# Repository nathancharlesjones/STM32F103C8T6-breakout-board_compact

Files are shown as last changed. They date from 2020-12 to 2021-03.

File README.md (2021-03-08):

# STM32F103C8T6 Breakout Board - Compact

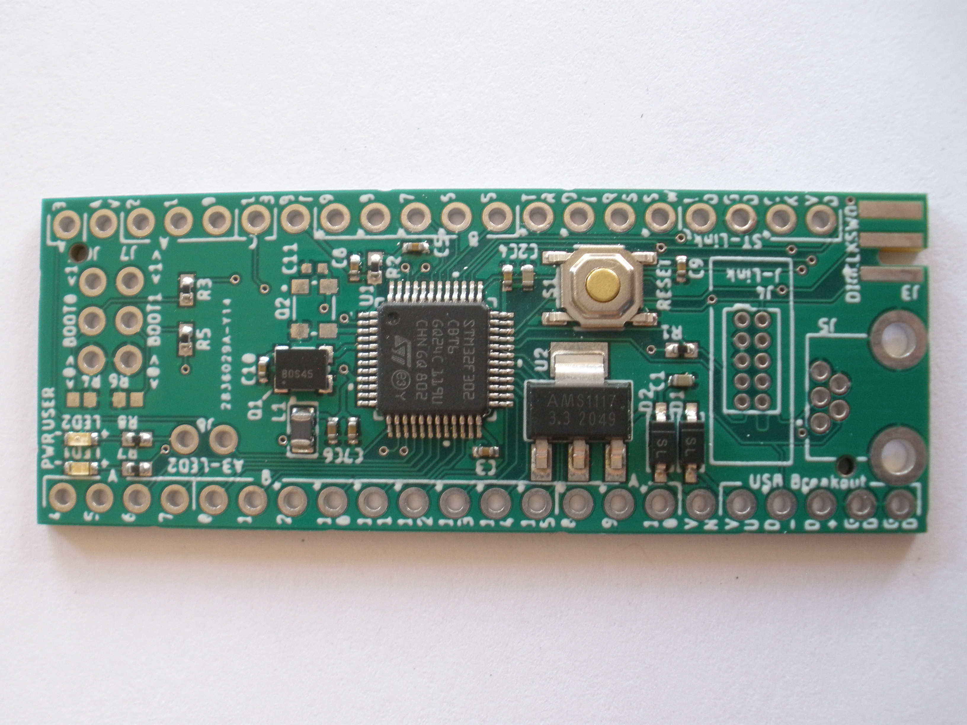
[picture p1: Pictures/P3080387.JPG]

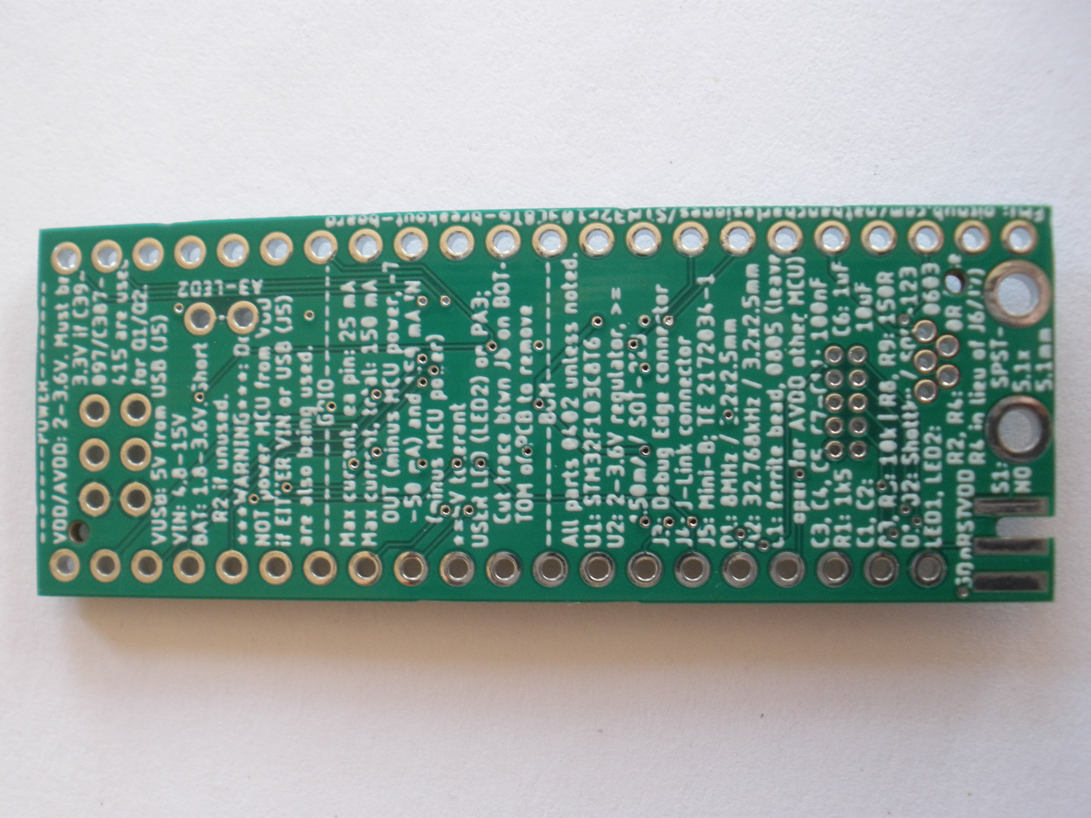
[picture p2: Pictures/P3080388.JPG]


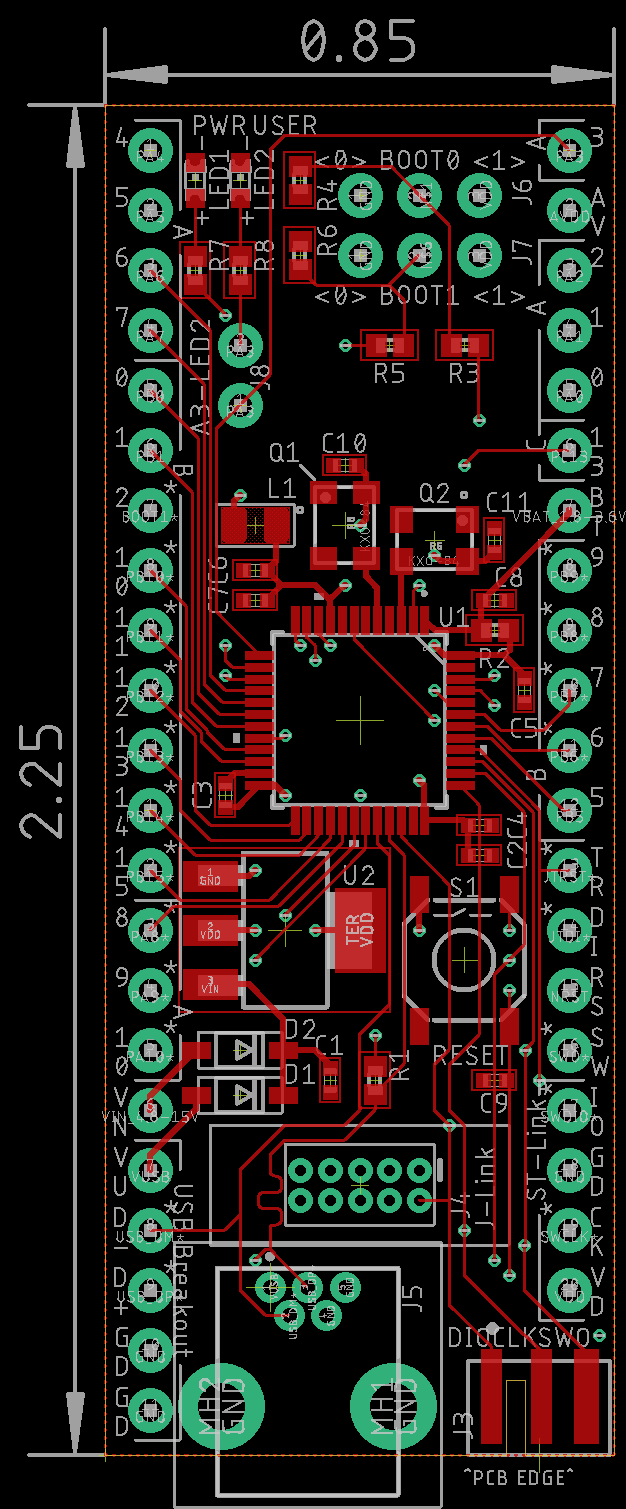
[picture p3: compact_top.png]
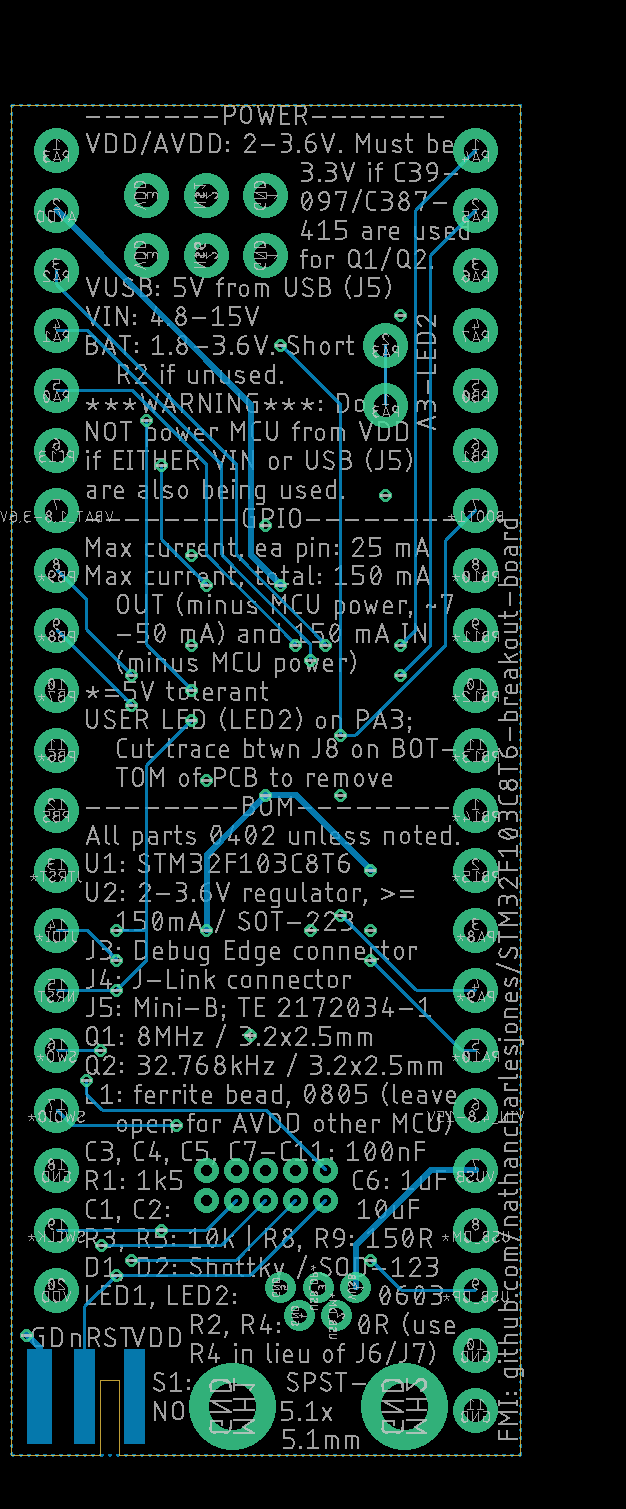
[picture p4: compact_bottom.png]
 

Breakout board for the venerable STM32F103C8T6 (a.k.a. the "Blue Pill") intended to be assembled by JLC PCB. For more information about this PCB and how to order one, visit [this Git repository](https://github.com/nathancharlesjones/STM32F103C8T6-breakout-board).

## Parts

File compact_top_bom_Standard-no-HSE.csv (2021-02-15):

Comment | Designator | Footprint | LCSC Part #
0R | R2 | R0402 | C17168
 | LED1 | D0603 | C72041
 | LED2 | D0603 | C72038
 | D1 D2 | SOD-123 | C8598
 | L1 | L0805 | C1015
1uF | C6 | C0402 | C52923
10k | R3 R5 | R0402 | C25744
10uF | C1 C2 | C0402 | C15525
100nF | C3 C4 C5 C7 C8 C9 | C0402 | C1525
150R | R7 R8 | R0402 | C25082
CJT1117-3.3-SOT223 | U2 | SOT-223 | C6186
MOMENTARY-SWITCH-SPST-SMD-5.2-REDUNDANT | S1 | TACTILE_SWITCH_SMD_5.2MM | C318884
STM32F103C8T6 | U1 | LQFP48-7X7MM | C8734

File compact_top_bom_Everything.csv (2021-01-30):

Comment | Designator | Footprint | LCSC Part #
0R | R2 R4 R6 | R0402 | C17168
 | Q1 | 3.2x2.5mm | C39097
 | Q2 | 3.2x2.5mm | C387415
 | LED1 | D0603 | C72041
 | LED2 | D0603 | C72038
 | D1 D2 | SOD-123 | C8598
 | L1 | L0805 | C1015
1k5 | R1 | R0402 | C25867
1uF | C6 | C0402 | C52923
10k | R3 R5 | R0402 | C25744
10uF | C1 C2 | C0402 | C15525
100nF | C3 C4 C5 C7 C8 C9 C10 C11 | C0402 | C1525
150R | R7 R8 | R0402 | C25082
CJT1117-3.3-SOT223 | U2 | SOT-223 | C6186
MOMENTARY-SWITCH-SPST-SMD-5.2-REDUNDANT | S1 | TACTILE_SWITCH_SMD_5.2MM | C318884
STM32F103C8T6 | U1 | LQFP48-7X7MM | C8734

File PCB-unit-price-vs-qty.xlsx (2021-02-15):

 |  |  |  |  |  |  | # PCBs: | 1 |  | 5 |  | 10 |  | 15 |  | 20
Comment | Designator | Footprint | LCSC Part # | PCB Qty | Price, Qty: 1 | "MOQ" | Needed Qty | Part cost | Needed Qty | Part cost | Needed Qty | Part cost | Needed Qty | Part cost | Needed Qty | Part cost
0R | R2 R4 R6 | R0402 | C17168 | 3 | $0.0011 | 40 | 3 | 0.044 | 15 | 0.044 | 30 | 0.044 | 45 | 0.0495 | 60 | 0.066
 | Q1 | 3.2x2.5mm | C39097 | 1 | $0.5343 | 10 | 1 | 5.343 | 5 | 5.343 | 10 | 5.343 | 15 | 8.0145 | 20 | 10.686
 | Q2 | 3.2x2.5mm | C387415 | 1 | $0.4300 | 10 | 1 | 4.3 | 5 | 4.3 | 10 | 4.3 | 15 | 6.45 | 20 | 8.6
 | LED1 | D0603 | C72041 | 1 | $0.0238 | 20 | 1 | 0.476 | 5 | 0.476 | 10 | 0.476 | 15 | 0.476 | 20 | 0.476
 | LED2 | D0603 | C72038 | 1 | $0.0243 | 20 | 1 | 0.486 | 5 | 0.486 | 10 | 0.486 | 15 | 0.486 | 20 | 0.486
 | D1 D2 | SOD-123 | C8598 | 2 | $0.0344 | 15 | 2 | 0.516 | 10 | 0.516 | 20 | 0.688 | 30 | 1.032 | 40 | 1.376
 | L1 | L0805 | C1015 | 1 | $0.0121 | 20 | 1 | 0.242 | 5 | 0.242 | 10 | 0.242 | 15 | 0.242 | 20 | 0.242
1k5 | R1 | R0402 | C25867 | 1 | $0.0011 | 40 | 1 | 0.044 | 5 | 0.044 | 10 | 0.044 | 15 | 0.044 | 20 | 0.044
1uF | C6 | C0402 | C52923 | 1 | $0.0071 | 40 | 1 | 0.284 | 5 | 0.284 | 10 | 0.284 | 15 | 0.284 | 20 | 0.284
10k | R3 R5 | R0402 | C25744 | 2 | $0.0011 | 40 | 2 | 0.044 | 10 | 0.044 | 20 | 0.044 | 30 | 0.044 | 40 | 0.044
10uF | C1 C2 | C0402 | C15525 | 2 | $0.0135 | 40 | 2 | 0.54 | 10 | 0.54 | 20 | 0.54 | 30 | 0.54 | 40 | 0.54
100nF | C3 C4 C5 C7 C8 C9 C10 C11 | C0402 | C1525 | 8 | $0.0029 | 40 | 8 | 0.116 | 40 | 0.116 | 80 | 0.232 | 120 | 0.348 | 160 | 0.464
150R | R7 R8 | R0402 | C25082 | 2 | $0.0011 | 40 | 2 | 0.044 | 10 | 0.044 | 20 | 0.044 | 30 | 0.044 | 40 | 0.044
CJT1117-3.3-SOT223 | U2 | SOT-223 | C6186 | 1 | $0.1193 | 2 | 1 | 0.2386 | 5 | 0.5965 | 10 | 1.193 | 15 | 1.7895 | 20 | 2.386
MOMENTARY-SWITCH-SPST-SMD-5.2-REDUNDANT | S1 | TACTILE_SWITCH_SMD_5.2MM | C318884 | 1 | $0.0219 | 5 | 1 | 0.1095 | 5 | 0.1095 | 10 | 0.219 | 15 | 0.3285 | 20 | 0.438
STM32F103C8T6 | U1 | LQFP48-7X7MM | C8734 | 1 |  | 2 | 1 |  | 5 |  | 10 |  | 15 |  | 20
 |  |  |  |  |  |  | Total | 12.8271 | Total | 13.185 | Total | 14.179 | Total | 20.172 | Total | 26.176
 |  |  |  |  |  |  | Total/PCB | 12.8271 | Total/PCB | 2.637 | Total/PCB | 1.4179 | Total/PCB | 1.3448 | Total/PCB | 1.3088

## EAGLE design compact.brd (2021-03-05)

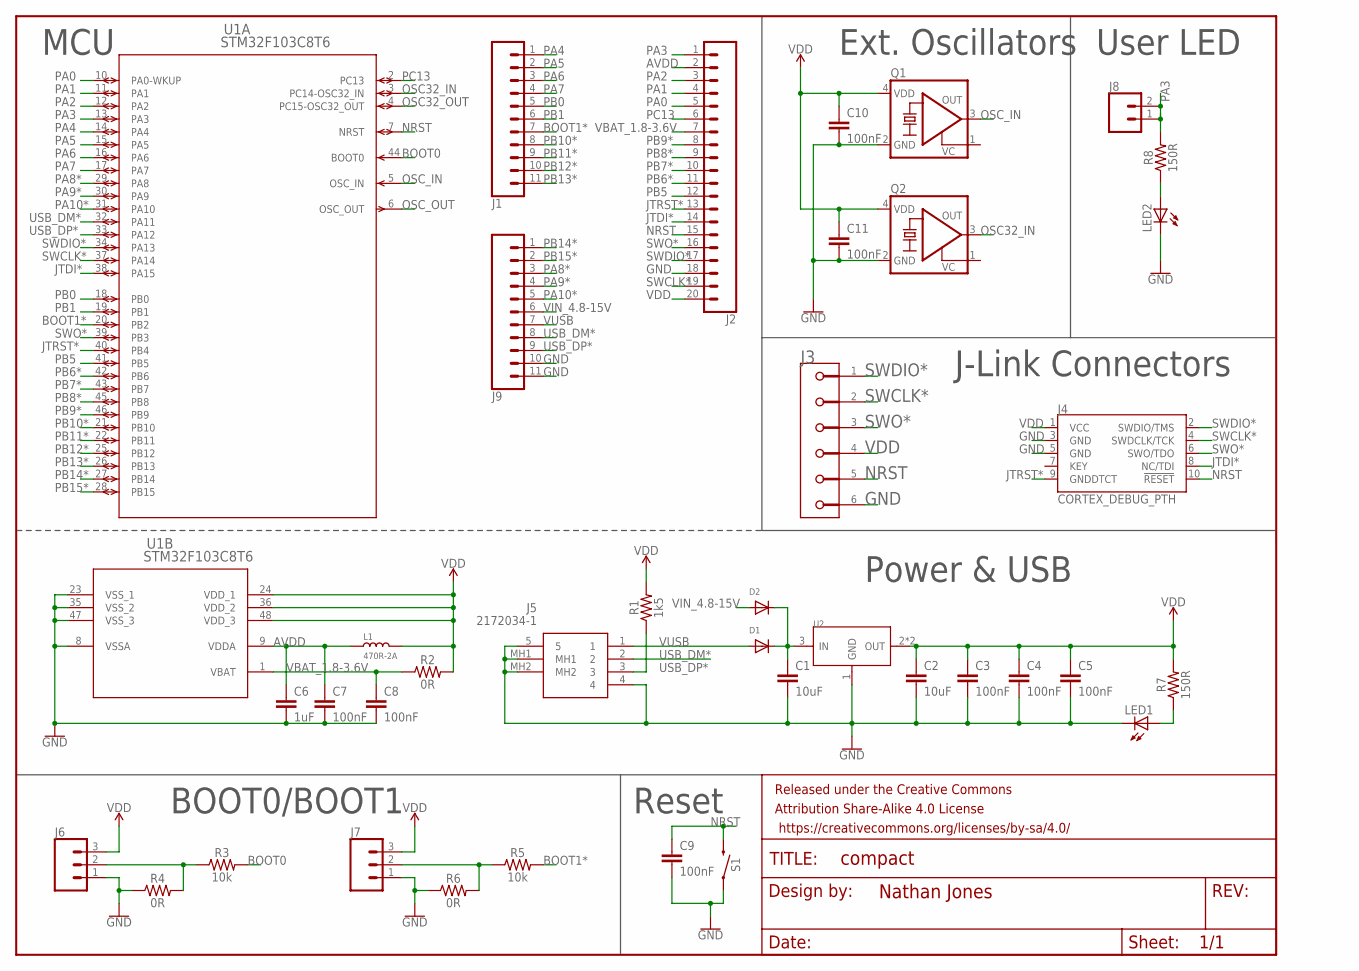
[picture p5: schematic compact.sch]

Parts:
C1, C2: 10uF; 0402-TIGHT; LCSC_PART C15525
C3, C4, C5, C7, C8, C9, C10, C11: 100nF; 0402-TIGHT; LCSC_PART C1525
C6: 1uF; 0402-TIGHT; LCSC_PART C52923
D1, D2: DIODESOD-123; SOD-123; LCSC_PART C8598
FRAME2: FRAME-LETTERNO_PACKAGE; DUMMY
J1, J9: CONN_111X11_NO_SILK; 1X11_NO_SILK
J2: CONN_20NOSILK; 1X20_NOSILK
J3: AVX_6-PIN_009159006061916_33MIL-GAP
J4: CORTEX_DEBUG_PTH; 2X5-PTH-1.27MM
J5: 2172034-1; 21720341
J6, J7: CONN_031X03_NO_SILK; 1X03_NO_SILK
J8: CONN_021X02_NO_SILK; 1X02_NO_SILK
L1: 470R-2A; L0805; LCSC_PART C1015
LED1: LEDCHIPLED_0603; CHIPLED_0603; LCSC_PART C72041
LED2: LEDCHIPLED_0603; CHIPLED_0603; LCSC_PART C72038
Q1: KXO-VCXO-CMOS_4; 3.2X2.5_KXO-84-TCXO; LCSC_PART C39097
Q2: KXO-VCXO-CMOS_4; 3.2X2.5_KXO-84-TCXO; LCSC_PART C387415
R1: 1k5; 0402; LCSC_PART C25867
R2, R4, R6: 0R; 0402; LCSC_PART C17168
R3, R5: 10k; 0402; LCSC_PART C25744
R7, R8: 150R; 0402; LCSC_PART C25082
S1: MOMENTARY-SWITCH-SPST-SMD-5.2-REDUNDANT; TACTILE_SWITCH_SMD_5.2MM; LCSC_PART C318884
U1: STM32F103C8T6; LQFP48-7X7MM; LCSC_PART C94046
U2: CJT1117-3.3-SOT223; SOT-223; LCSC_PART C6186

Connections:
AVDD: C6.1, C7.1, J2.2, L1.1, U1.9 (VDDA)
BOOT0: R3.2, U1.44 (BOOT0)
BOOT1*: J1.7, R5.2, U1.20 (PB2)
GND: C1.2, C2.2, C3.2, C4.2, C5.2, C6.2, C7.2, C8.2, C9.2, C10.2, C11.2, J2.18, J3.6, J4.3 (GND), J4.5 (GND), J5.4, J5.5, J5.MH1, J5.MH2, J6.1, J7.1, J9.10, J9.11, LED1.C, LED2.C, Q1.2 (GND), Q2.2 (GND), R4.1, R6.1, S1.1, S1.2 (1), U1.8 (VSSA), U1.23 (VSS_1), U1.35 (VSS_2), U1.47 (VSS_3), U2.1 (GND)
JTDI*: J2.14, J4.8 (NC/TDI), U1.38 (PA15)
JTRST*: J2.13, J4.9 (GNDDTCT), U1.40 (PB4)
unnamed: J6.2, R3.1, R4.2
unnamed: LED2.A, R8.1
unnamed: J7.2, R5.1, R6.2
unnamed: LED1.A, R7.1
NRST: C9.1, J2.15, J3.5, J4.10 (!RESET), S1.3 (2), S1.4 (2), U1.7 (NRST)
OSC32_IN: Q2.3 (OUT), U1.3 (PC14-OSC32_IN)
OSC32_OUT: U1.4 (PC15-OSC32_OUT)
OSC_IN: Q1.3 (OUT), U1.5 (OSC_IN)
OSC_OUT: U1.6 (OSC_OUT)
PA0: J2.5, U1.10 (PA0-WKUP)
PA1: J2.4, U1.11 (PA1)
PA2: J2.3, U1.12 (PA2)
PA3: J2.1, J8.1, J8.2, R8.2, U1.13 (PA3)
PA4: J1.1, U1.14 (PA4)
PA5: J1.2, U1.15 (PA5)
PA6: J1.3, U1.16 (PA6)
PA7: J1.4, U1.17 (PA7)
PA8*: J9.3, U1.29 (PA8)
PA9*: J9.4, U1.30 (PA9)
PA10*: J9.5, U1.31 (PA10)
PB0: J1.5, U1.18 (PB0)
PB1: J1.6, U1.19 (PB1)
PB5: J2.12, U1.41 (PB5)
PB6*: J2.11, U1.42 (PB6)
PB7*: J2.10, U1.43 (PB7)
PB8*: J2.9, U1.45 (PB8)
PB9*: J2.8, U1.46 (PB9)
PB10*: J1.8, U1.21 (PB10)
PB11*: J1.9, U1.22 (PB11)
PB12*: J1.10, U1.25 (PB12)
PB13*: J1.11, U1.26 (PB13)
PB14*: J9.1, U1.27 (PB14)
PB15*: J9.2, U1.28 (PB15)
PC13: J2.6, U1.2 (PC13)
SWCLK*: J2.19, J3.2, J4.4 (SWDCLK/TCK), U1.37 (PA14)
SWDIO*: J2.17, J3.1, J4.2 (SWDIO/TMS), U1.34 (PA13)
SWO*: J2.16, J3.3, J4.6 (SWO/TDO), U1.39 (PB3)
USB_DM*: J5.2, J9.8, U1.32 (PA11)
USB_DP*: J5.3, J9.9, R1.1, U1.33 (PA12)
VBAT_1.8-3.6V: C8.1, J2.7, R2.1, U1.1 (VBAT)
VDD: C2.1, C3.1, C4.1, C5.1, C10.1, C11.1, J2.20, J3.4, J4.1 (VCC), J6.3, J7.3, L1.2, Q1.4 (VDD), Q2.4 (VDD), R1.2, R2.2, R7.2, U1.24 (VDD_1), U1.36 (VDD_2), U1.48 (VDD_3), U2.2 (OUT), U2.TER (OUT)
VIN: C1.1, D1.C, D2.C, U2.3 (IN)
VIN_4.8-15V: D2.A, J9.6
VUSB: D1.A, J5.1, J9.7

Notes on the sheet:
MCU
Power & USB
Reset
BOOT0/BOOT1
Ext. Oscillators
User LED
J-Link Connectors

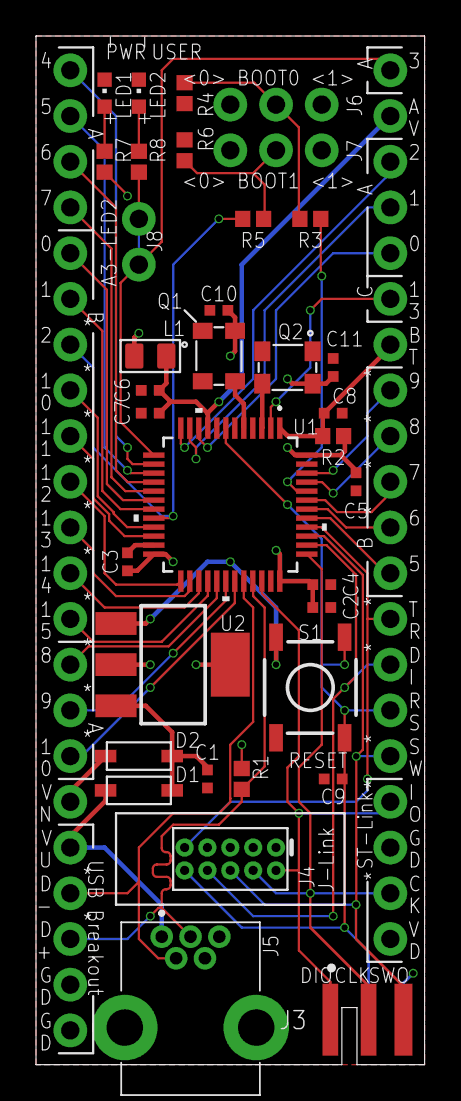
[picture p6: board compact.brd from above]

Board: 2 copper layers, 21.6 x 57.1 mm, 39 parts (0 on the bottom side), 48 nets.

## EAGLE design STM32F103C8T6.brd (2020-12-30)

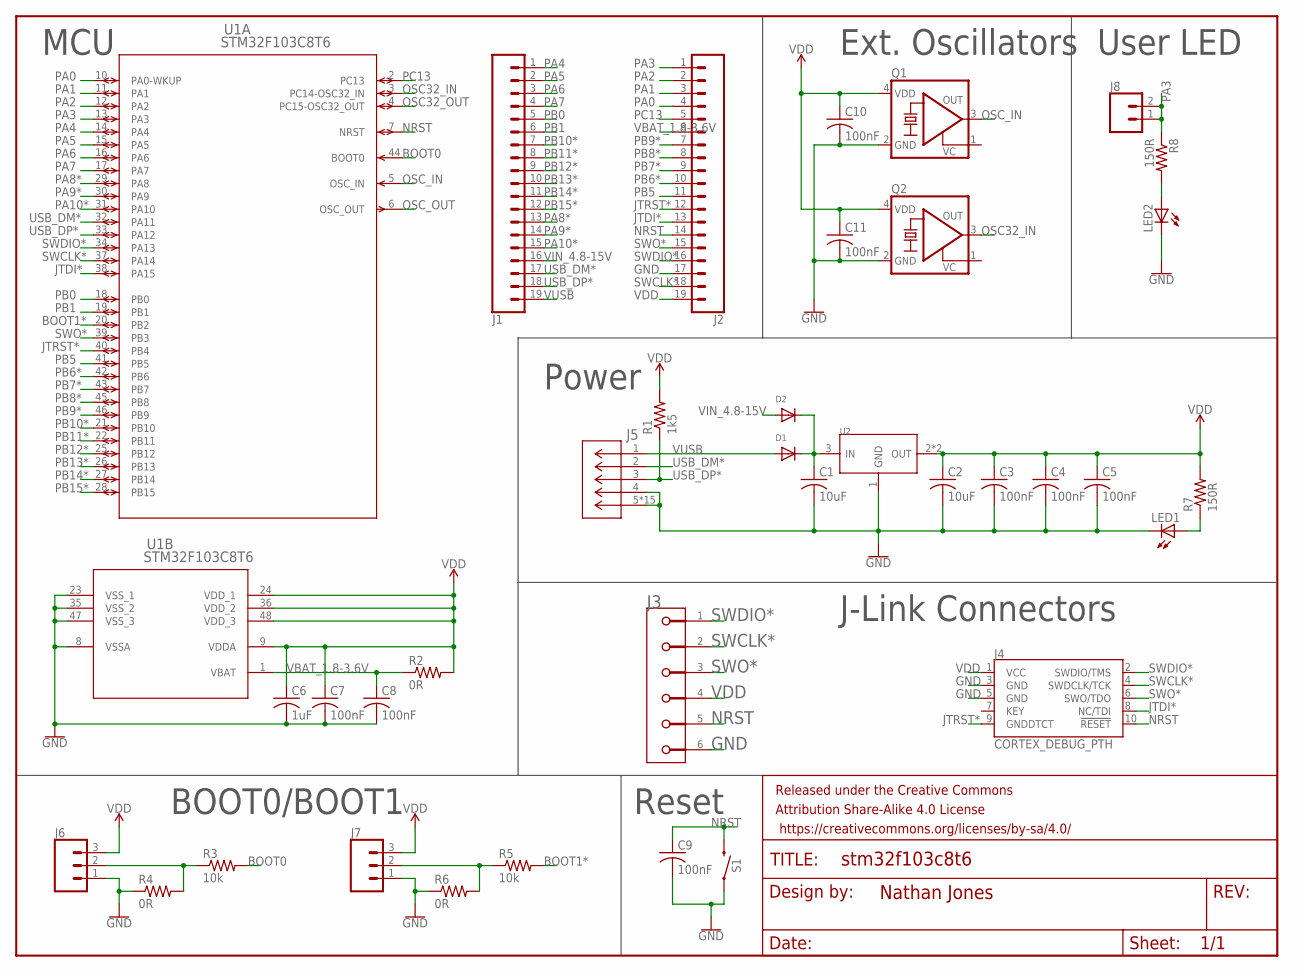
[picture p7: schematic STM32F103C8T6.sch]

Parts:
C1, C2: 10uF; C0402; LCSC_PART C15525
C3, C4, C5, C7, C8, C9, C10, C11: 100nF; C0402; LCSC_PART C1525
C6: 1uF; C0402; LCSC_PART C52923
D1, D2: DIODESOD-123; SOD-123; LCSC_PART C8598
FRAME2: FRAME-LETTERNO_PACKAGE; DUMMY
J1, J2: CONN_191X19_NO_SILK; 1X19_NO_SILK
J3: AVX_6-PIN_009159006061916; AVX_6-PIN_009159006061916_0
J4: CORTEX_DEBUG_PTH; 2X5-PTH-1.27MM
J5: 10118194-0001LF; CONN_10118194-0001LF_AMP
J6, J7: CONN_031X03_NO_SILK; 1X03_NO_SILK
J8: CONN_021X02_NO_SILK; 1X02_NO_SILK
LED1: LEDCHIPLED_0603; CHIPLED_0603; LCSC_PART C72041
LED2: LEDCHIPLED_0603; CHIPLED_0603; LCSC_PART C72038
Q1: KXO-VCXO-CMOS_4; 3.2X2.5_KXO-84-TCXO; LCSC_PART C39097
Q2: KXO-VCXO-CMOS_4; 3.2X2.5_KXO-84-TCXO; LCSC_PART C387415
R1: 1k5; R0402; LCSC_PART C25867
R2, R4, R6: 0R; R0402; LCSC_PART C17168
R3, R5: 10k; R0402; LCSC_PART C25744
R7, R8: 150R; R0402; LCSC_PART C25082
S1: MOMENTARY-SWITCH-SPST-SMD-5.2-REDUNDANT; TACTILE_SWITCH_SMD_5.2MM; LCSC_PART C318884
U1: STM32F103C8T6; LQFP48-7X7MM; LCSC_PART C94046
U2: CJT1117-3.3-SOT223; SOT-223; LCSC_PART C6186

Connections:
BOOT0: R3.2, U1.44 (BOOT0)
BOOT1*: R5.2, U1.20 (PB2)
GND: C1.2, C2.2, C3.2, C4.2, C5.2, C6.2, C7.2, C8.2, C9.2, C10.2, C11.2, J2.17, J3.6, J4.3 (GND), J4.5 (GND), J5.4, J5.5, J5.10 (5), J5.11 (5), J5.S_1 (5), J5.S_1_H1 (5), J5.S_1_H2 (5), J5.S_2 (5), J5.S_2_H1 (5), J5.S_2_H2 (5), J5.S_3 (5), J5.S_3_H1 (5), J5.S_3_H2 (5), J5.S_4 (5), J5.S_4_H1 (5), J5.S_4_H2 (5), J6.1, J7.1, LED1.C, LED2.C, Q1.2 (GND), Q2.2 (GND), R4.1, R6.1, S1.1, S1.2 (1), U1.8 (VSSA), U1.23 (VSS_1), U1.35 (VSS_2), U1.47 (VSS_3), U2.1 (GND)
JTDI*: J2.13, J4.8 (NC/TDI), U1.38 (PA15)
JTRST*: J2.12, J4.9 (GNDDTCT), U1.40 (PB4)
unnamed: J6.2, R3.1, R4.2
unnamed: LED2.A, R8.2
unnamed: J7.2, R5.1, R6.2
unnamed: LED1.A, R7.1
NRST: C9.1, J2.14, J3.5, J4.10 (!RESET), S1.3 (2), S1.4 (2), U1.7 (NRST)
OSC32_IN: Q2.3 (OUT), U1.3 (PC14-OSC32_IN)
OSC32_OUT: U1.4 (PC15-OSC32_OUT)
OSC_IN: Q1.3 (OUT), U1.5 (OSC_IN)
OSC_OUT: U1.6 (OSC_OUT)
PA0: J2.4, U1.10 (PA0-WKUP)
PA1: J2.3, U1.11 (PA1)
PA2: J2.2, U1.12 (PA2)
PA3: J2.1, J8.1, J8.2, R8.1, U1.13 (PA3)
PA4: J1.1, U1.14 (PA4)
PA5: J1.2, U1.15 (PA5)
PA6: J1.3, U1.16 (PA6)
PA7: J1.4, U1.17 (PA7)
PA8*: J1.13, U1.29 (PA8)
PA9*: J1.14, U1.30 (PA9)
PA10*: J1.15, U1.31 (PA10)
PB0: J1.5, U1.18 (PB0)
PB1: J1.6, U1.19 (PB1)
PB5: J2.11, U1.41 (PB5)
PB6*: J2.10, U1.42 (PB6)
PB7*: J2.9, U1.43 (PB7)
PB8*: J2.8, U1.45 (PB8)
PB9*: J2.7, U1.46 (PB9)
PB10*: J1.7, U1.21 (PB10)
PB11*: J1.8, U1.22 (PB11)
PB12*: J1.9, U1.25 (PB12)
PB13*: J1.10, U1.26 (PB13)
PB14*: J1.11, U1.27 (PB14)
PB15*: J1.12, U1.28 (PB15)
PC13: J2.5, U1.2 (PC13)
SWCLK*: J2.18, J3.2, J4.4 (SWDCLK/TCK), U1.37 (PA14)
SWDIO*: J2.16, J3.1, J4.2 (SWDIO/TMS), U1.34 (PA13)
SWO*: J2.15, J3.3, J4.6 (SWO/TDO), U1.39 (PB3)
USB_DM*: J1.17, J5.2, U1.32 (PA11)
USB_DP*: J1.18, J5.3, R1.1, U1.33 (PA12)
VBAT_1.8-3.6V: C8.1, J2.6, R2.1, U1.1 (VBAT)
VDD: C2.1, C3.1, C4.1, C5.1, C6.1, C7.1, C10.1, C11.1, J2.19, J3.4, J4.1 (VCC), J6.3, J7.3, Q1.4 (VDD), Q2.4 (VDD), R1.2, R2.2, R7.2, U1.9 (VDDA), U1.24 (VDD_1), U1.36 (VDD_2), U1.48 (VDD_3), U2.2 (OUT), U2.TER (OUT)
VIN: C1.1, D1.C, D2.C, U2.3 (IN)
VIN_4.8-15V: D2.A, J1.16
VUSB: D1.A, J1.19, J5.1

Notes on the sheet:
MCU
Power
Reset
BOOT0/BOOT1
Ext. Oscillators
User LED
J-Link Connectors

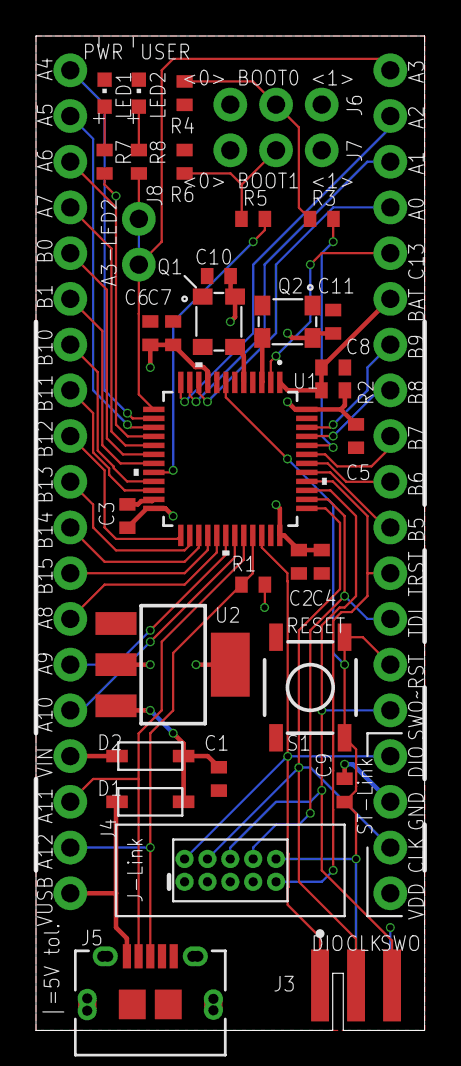
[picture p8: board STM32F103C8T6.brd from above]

Board: 2 copper layers, 21.6 x 55.2 mm, 37 parts (0 on the bottom side), 47 nets.

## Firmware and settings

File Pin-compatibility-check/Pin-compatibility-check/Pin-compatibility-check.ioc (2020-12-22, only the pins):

Mcu.UserName=STM32F103C8Tx
PA13.Signal=SYS_JTMS-SWDIO
PA14.Signal=SYS_JTCK-SWCLK
PA15.Signal=SYS_JTDI
PB3.Signal=SYS_JTDO-TRACESWO
PB4.Signal=SYS_NJTRST

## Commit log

2020-12-20 Copied over STM32F0 schematic. Updated MCU and several other components.
    [STM32F103C8T6.brd, STM32F103C8T6.sch]
2020-12-21 Added power capacitors. Added new LSE oscillator.
    [STM32F103C8T6.brd, STM32F103C8T6.sch]
2020-12-22 Nearly finalized circuit.
    [STM32F103C8T6.brd, STM32F103C8T6.sch]
2020-12-28 Nearly finished layout.
    [STM32F103C8T6.brd, STM32F103C8T6.sch]
2020-12-30 Finished layout.
    [STM32F103C8T6.brd, STM32F103C8T6.sch, STM32F103C8T6_top_bom.csv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]
2021-01-02 Updated files.
    [Pin-compatible-comparison.ods, STM32F103C8T6-breakout-board_compact.brd, STM32F103C8T6-breakout-board_compact.sch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]
2021-01-02 Renamed files.
    [STM32F103C8T6_top_bom.csv, compact.brd, compact.sch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]
2021-01-02 Removed libraries, Reference, and Pin-Compatibility-Check folders.
    [Pin-compatible-comparison.ods]
2021-01-04 Added screenshots.
    [compact.brd, compact_top_bom_Everything.csv, compact_top_bom_Minimum.csv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]
2021-01-05 Updated screenshots.
    [compact.brd]
2021-01-30 Changed USB connector to mini-B. Change pin labels on the silkscreen to be more readable.
    [compact.brd, compact.sch, compact_top_bom_Everything.csv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]
2021-01-30 Updated AVX footprint.
    [compact.brd, compact.sch]
2021-02-15 Separated Standard configuration into Standard-no-HSE and Standard-with-HSE configurations.
    [compact.brd, compact.sch, compact_top_bom_Standard-no-HSE.csv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]
2021-03-05 Updated Debug Edge library. Updated Gerbers, screenshots, and schematic image. Switched to new Mini-B USB footprint.
    [compact.brd, compact.sch]

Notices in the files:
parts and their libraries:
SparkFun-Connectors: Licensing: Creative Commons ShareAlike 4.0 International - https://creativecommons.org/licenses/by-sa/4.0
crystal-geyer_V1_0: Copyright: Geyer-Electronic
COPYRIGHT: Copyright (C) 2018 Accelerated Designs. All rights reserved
